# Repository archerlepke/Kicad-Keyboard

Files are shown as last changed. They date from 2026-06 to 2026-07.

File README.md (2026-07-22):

# Custom 60% Keyboard From Scratch

A custom mechanical keyboard designed from scratch in KiCad — schematic, PCB, and supporting files.

The goal of this repo is to document and archive my completed work on this project.

## Current Status

> **Manufacturing & Physical Assembly** — The PCB design is complete and the board has been sent to manufacturing.

Future Plans:
- soldering components & microcontroller from digikey(already bought and delivered)
- 3D Print keyboard case
- install switches & keycaps (already bought and on hand)
- install firmware (QMK)

## Renders & PCB Design

The case for the keyboard has been designed and needs to be 3D printed.

**SolidWorks renders of completed case & PCB:**

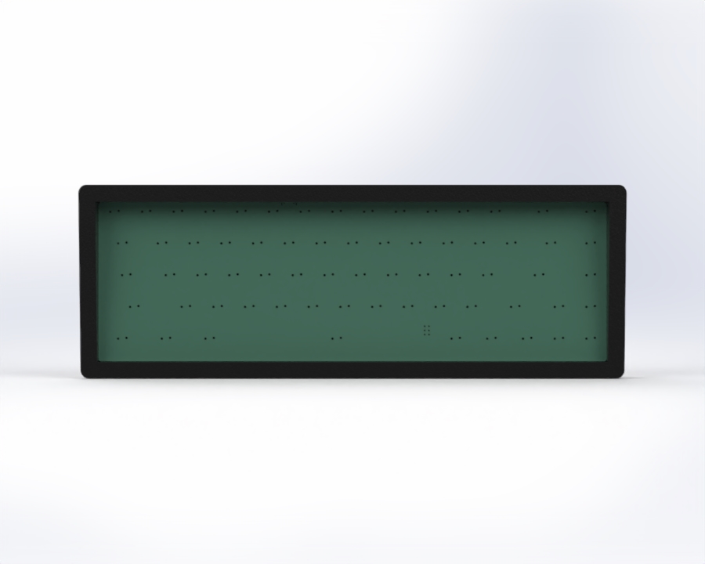
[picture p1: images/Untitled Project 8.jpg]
Render 2


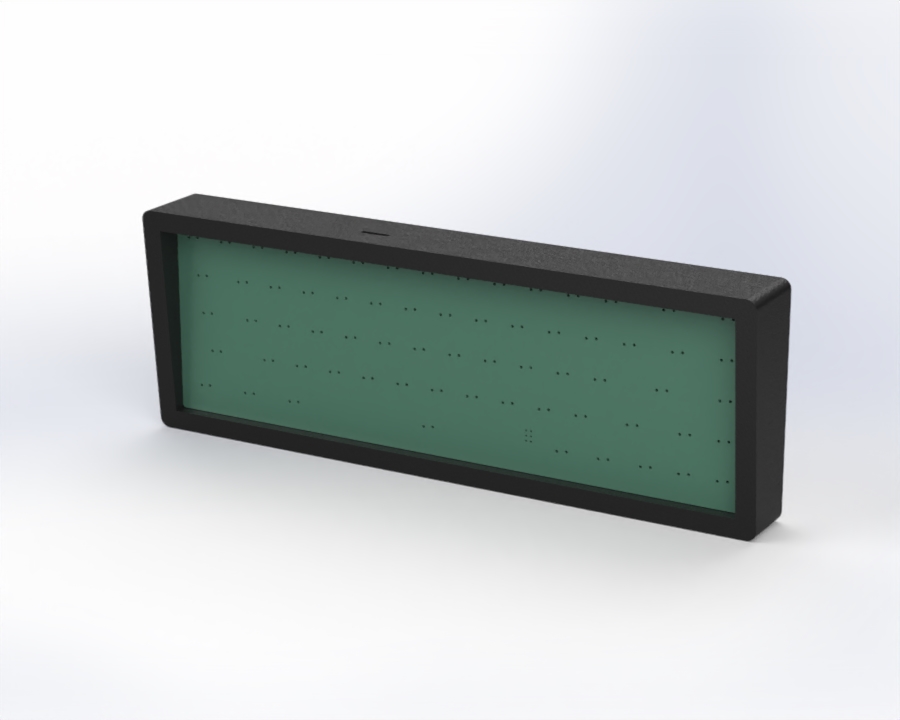
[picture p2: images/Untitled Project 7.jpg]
Render 1


**KiCad renders:**

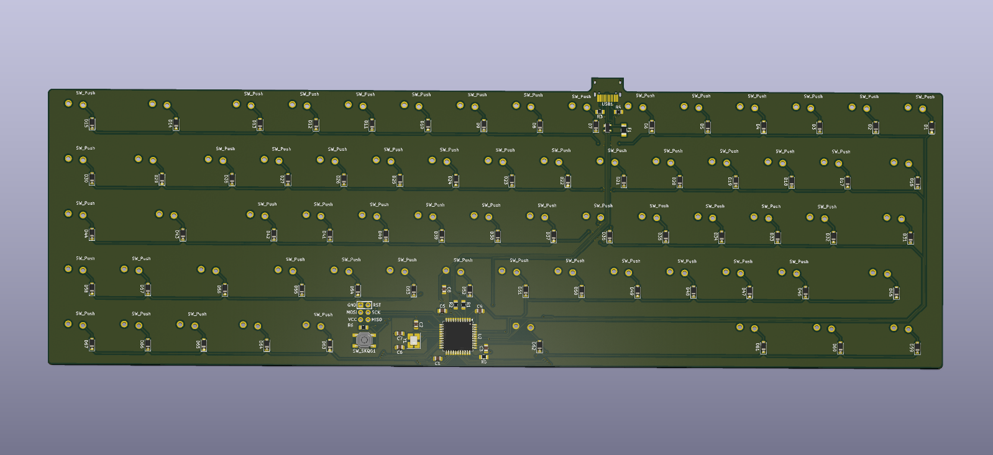
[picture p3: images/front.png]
KiCad Render 1


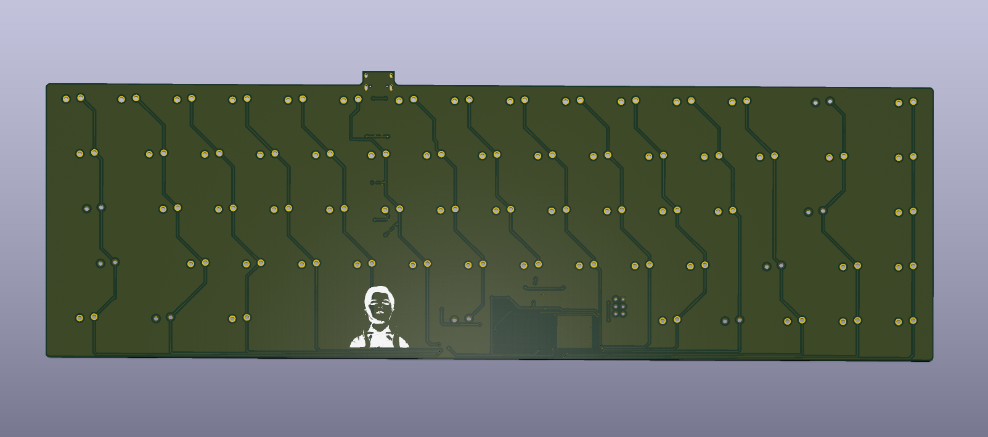
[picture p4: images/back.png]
KiCad Render 2


**KiCad PCB editor view & schematic:**

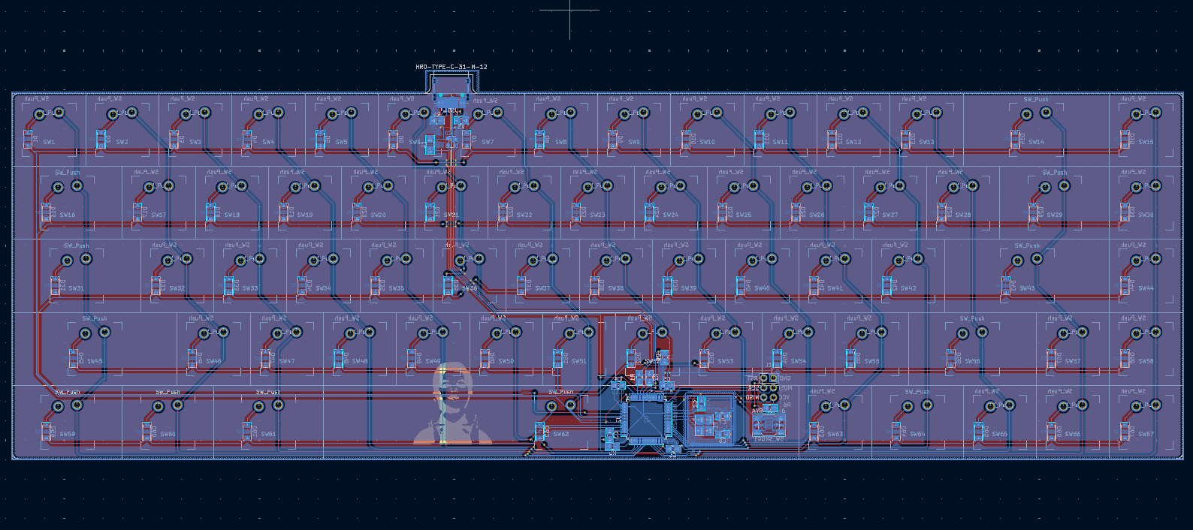
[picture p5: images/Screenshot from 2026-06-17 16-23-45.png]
PCB view 1


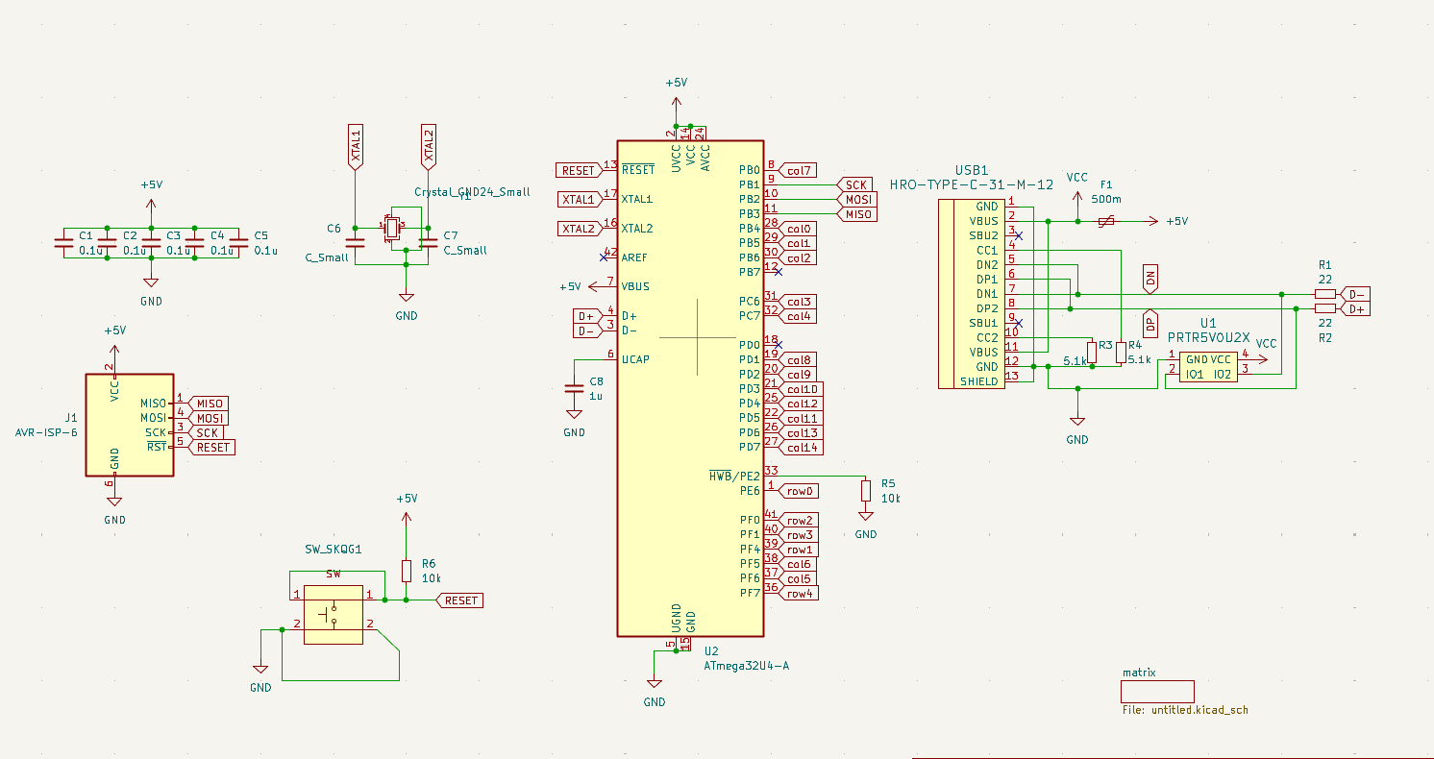
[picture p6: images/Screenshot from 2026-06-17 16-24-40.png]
PCB view 2


## About the Build

The goal of this build was to expand my electronics knowledge while physically creating a project I'd be proud of. This keyboard was designed following the excellent guide by Masterzen, [**Designing a keyboard from scratch**](https://www.masterzen.fr/2020/05/03/designing-a-keyboard-part-1/).

## Repository Structure

```
Keyboard/      KiCad project — open Keyboard/Keyboard.kicad_pro
libraries/     All footprint & symbol libraries (bundled, project-relative paths)
production/    Gerbers, drill files, and BOM as sent to manufacturing
cad/           STEP export and SolidWorks files for the case
images/        Renders and screenshots
```

## Opening the Project

```
git clone https://github.com/archerlepke/Kicad-Keyboard.git
```

Open `Keyboard/Keyboard.kicad_pro` in KiCad (v7 or newer). All custom libraries are
included in the repo and referenced with project-relative paths, so no library
setup is required.

## Library Credits

- [MX_Alps_Hybrid](https://github.com/ai03-2725/MX_Alps_Hybrid) — switch footprints & symbols by ai03
- [Type-C](https://github.com/ai03-2725/Type-C.pretty) — USB-C footprints & symbols by ai03
- [random-keyboard-parts](https://github.com/ai03-2725/random-keyboard-parts.pretty) — misc keyboard parts by ai03

## Tools Used

- **KiCad** — schematic capture and PCB design
- **SolidWorks** — 3D modeling
- **SolidWorks Visualize** — renders
- **QMK** — keyboard firmware (planned)

---

*This is an ongoing project*

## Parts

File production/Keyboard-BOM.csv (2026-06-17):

Id | Designator | Footprint | Quantity | Designation | Supplier and ref
1 | C1, C2, C3, C4, C5 | C_0805_2012Metric_Pad1.15x1.40mm_HandSolder | 5 | 0.1u
2 | C6, C7 | C_0805_2012Metric_Pad1.15x1.40mm_HandSolder | 2 | C_Small
3 | C8 | C_0805_2012Metric_Pad1.15x1.40mm_HandSolder | 1 | 1u
4 | D1, D2, D3, D4, D5, D6, D7, D8, D9, D10, D11, D12, D13, D14, D15, D16, D17, D18, D19, D20, D21, D22, D23, D24, D25, D26, D27, D28, D29, D30, D31, D32, D33, D34, D35, D36, D37, D38, D39, D40, D41, D42, D43, D44, D45, D46, D47, D48, D49, D50, D51, D52, D53, D54, D55, D56, D57, D58, D59, D60, D61, D62, D63, D64, D65, D66, D67 | D_SOD-123 | 67 | D
5 | F1 | Fuse_1206_3216Metric_Pad1.42x1.75mm_HandSolder | 1 | 500m
6 | J1 | Reset_Pretty-Mask | 1 | AVR-ISP-6
7 | R1, R2 | R_0805_2012Metric_Pad1.15x1.40mm_HandSolder | 2 | 22
8 | R3, R4 | R_0805_2012Metric_Pad1.15x1.40mm_HandSolder | 2 | 5.1k
9 | R5, R6 | R_0805_2012Metric_Pad1.15x1.40mm_HandSolder | 2 | 10k
10 | REF** | Untitled | 1 | Untitled
11 | SW1, SW2, SW3, SW4, SW5, SW6, SW7, SW8, SW9, SW10, SW11, SW12, SW13, SW15, SW17, SW18, SW19, SW20, SW21, SW22, SW23, SW24, SW25, SW26, SW27, SW28, SW30, SW32, SW33, SW34, SW35, SW36, SW37, SW38, SW39, SW40, SW41, SW42, SW44, SW46, SW47, SW48, SW49, SW50, SW51, SW52, SW53, SW54, SW55, SW57, SW58, SW63, SW65, SW66, SW67 | ALPS-1U | 55 | SW_Push
12 | SW14 | ALPS-2U | 1 | SW_Push
13 | SW16, SW29, SW59, SW61 | ALPS-1.5U | 4 | SW_Push
14 | SW31, SW56 | ALPS-1.75U | 2 | SW_Push
15 | SW43, SW45 | ALPS-2.25U | 2 | SW_Push
16 | SW60, SW64 | ALPS-1.25U | 2 | SW_Push
17 | SW62 | ALPS-6.5U | 1 | SW_Push
18 | SW_SKQG1 | SW_SPST_SKQG_WithStem | 1 | ~
19 | U1 | SOT143B | 1 | PRTR5V0U2X
20 | U2 | TQFP-44_10x10mm_P0.8mm | 1 | ATmega32U4-A
21 | USB1 | HRO-TYPE-C-31-M-12-HandSoldering | 1 | HRO-TYPE-C-31-M-12
22 | Y1 | Crystal_SMD_3225-4Pin_3.2x2.5mm_HandSoldering | 1 | Crystal_GND24_Small | got

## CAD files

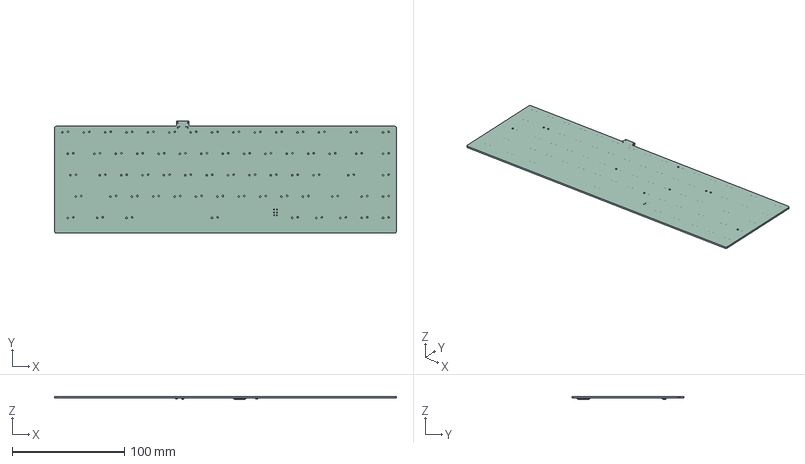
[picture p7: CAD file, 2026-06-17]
Keyboard/.step
304.8 x 100.0 x 2.70 mm
SOT-143
Fuse_1206_3216Metric
Crystal_SMD_3225-4Pin_3.2x2.5mm
TQFP-44_10x10mm_P0.8mm
Keyboard_PCB

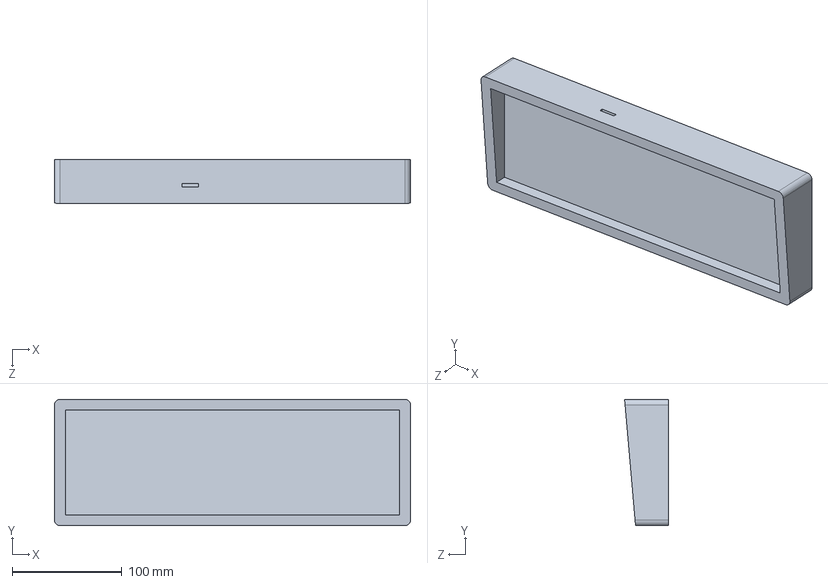
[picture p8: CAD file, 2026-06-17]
cad/dumb.SLDPRT
324.8 x 115.2 x 40.0 mm

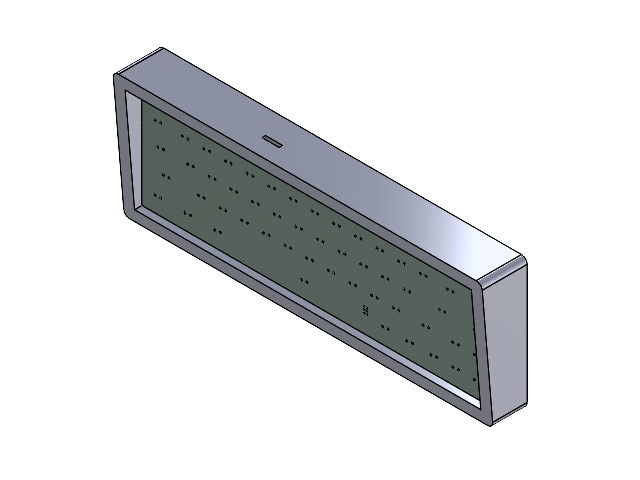
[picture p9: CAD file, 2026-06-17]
cad/Assembly.SLDASM
dumb
SOT-143.step
Fuse_1206_3216Metric.step
Crystal_SMD_3225-4Pin_3.2x2.5mm.step
TQFP-44_10x10mm_P0.8mm.step
Keyboard_PCB.step

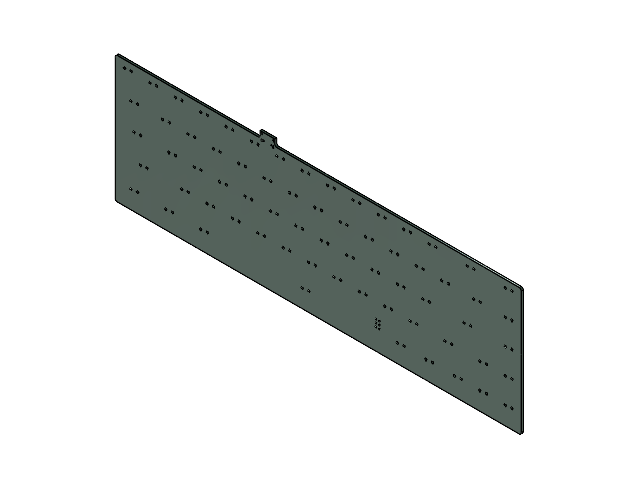
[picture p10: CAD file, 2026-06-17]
cad/part.SLDASM
SOT-143.step
Fuse_1206_3216Metric.step
Crystal_SMD_3225-4Pin_3.2x2.5mm.step
TQFP-44_10x10mm_P0.8mm.step
Keyboard_PCB.step

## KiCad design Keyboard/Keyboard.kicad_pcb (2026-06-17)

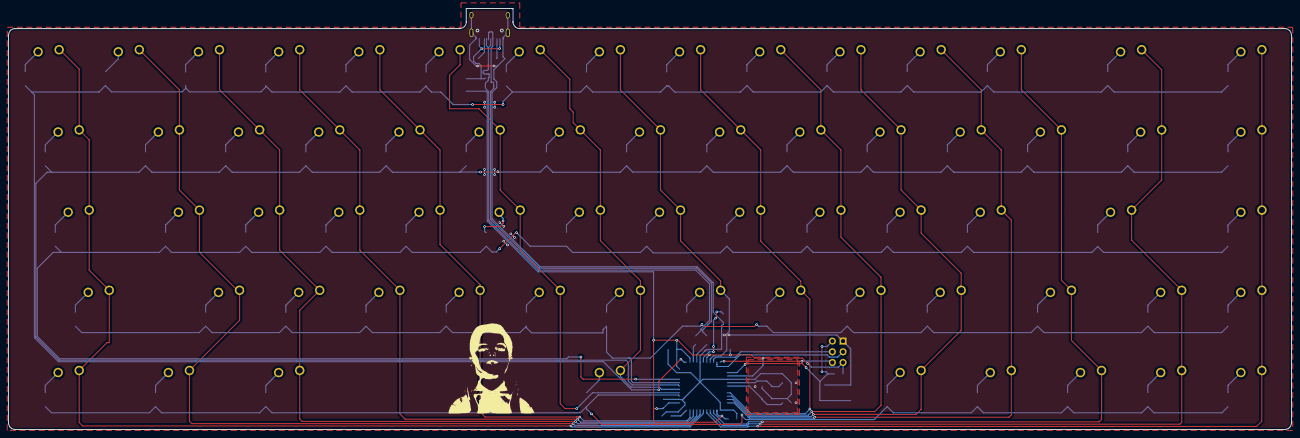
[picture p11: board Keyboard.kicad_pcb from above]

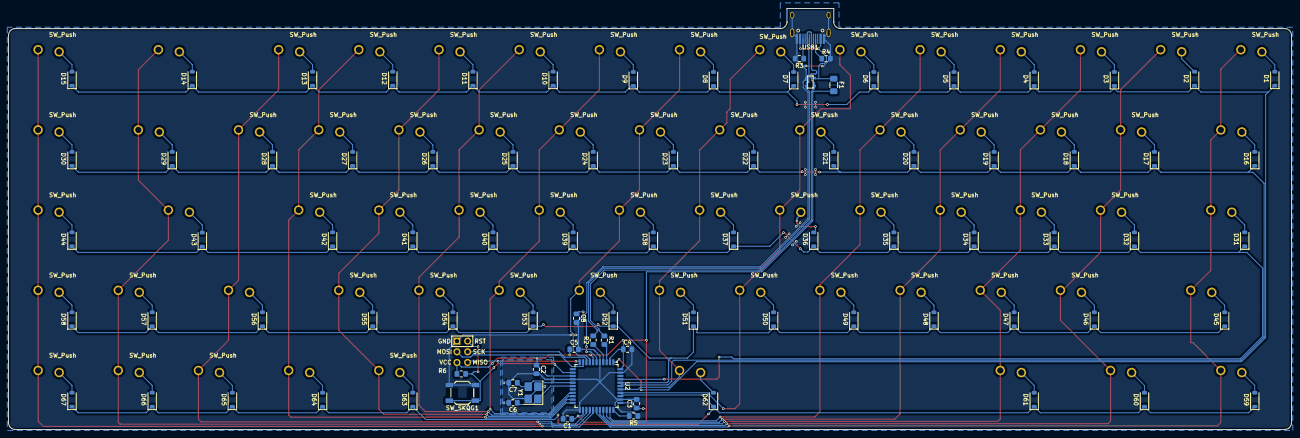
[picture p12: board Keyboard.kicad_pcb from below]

Board: 2 copper layers, 304.8 x 100.0 mm, 155 parts (88 on the bottom side), 104 nets.

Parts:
C1, C2, C3, C4, C5: 0.1u; C_0805_2012Metric_Pad1.15x1.40mm_HandSolder
C6, C7: C_Small; C_0805_2012Metric_Pad1.15x1.40mm_HandSolder
C8: 1u; C_0805_2012Metric_Pad1.15x1.40mm_HandSolder
D1, D2, D3, D4, D5, D6, D7, D8, D9, D10, D11, D12, D13, D14, D15, D16, D17, D18, D19, D20, D21, D22, D23, D24, D25, D26, D27, D28, D29, D30, D31, D32, D33, D34, D35, D36, D37, D38, D39, D40, D41, D42, D43, D44, D45, D46, D47, D48, D49, D50, D51, D52, D53, D54, D55, D56, D57, D58, D59, D60, D61, D62, D63, D64, D65, D66, D67: D; D_SOD-123
F1: 500m; Fuse_1206_3216Metric_Pad1.42x1.75mm_HandSolder
J1: AVR-ISP-6; Reset_Pretty-Mask
R1, R2: 22; R_0805_2012Metric_Pad1.15x1.40mm_HandSolder
R3, R4: 5.1k; R_0805_2012Metric_Pad1.15x1.40mm_HandSolder
R5, R6: 10k; R_0805_2012Metric_Pad1.15x1.40mm_HandSolder
SW1, SW2, SW3, SW4, SW5, SW6, SW7, SW8, SW9, SW10, SW11, SW12, SW13, SW15, SW17, SW18, SW19, SW20, SW21, SW22, SW23, SW24, SW25, SW26, SW27, SW28, SW30, SW32, SW33, SW34, SW35, SW36, SW37, SW38, SW39, SW40, SW41, SW42, SW44, SW46, SW47, SW48, SW49, SW50, SW51, SW52, SW53, SW54, SW55, SW57, SW58, SW63, SW65, SW66, SW67: SW_Push; ALPS-1U
SW14: SW_Push; ALPS-2U
SW16, SW29, SW59, SW61: SW_Push; ALPS-1.5U
SW31, SW56: SW_Push; ALPS-1.75U
SW43, SW45: SW_Push; ALPS-2.25U
SW60, SW64: SW_Push; ALPS-1.25U
SW62: SW_Push; ALPS-6.5U
SW_SKQG1: SW_SPST_SKQG_WithStem
U1: PRTR5V0U2X; SOT143B
U2: ATmega32U4-A; TQFP-44_10x10mm_P0.8mm
USB1: HRO-TYPE-C-31-M-12; HRO-TYPE-C-31-M-12-HandSoldering
Y1: Crystal_GND24_Small; Crystal_SMD_3225-4Pin_3.2x2.5mm_HandSoldering

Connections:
+5V: C1.1, C2.1, C3.1, C4.1, C5.1, F1.2, J1.2 (VCC), R6.1, U2.2 (UVCC), U2.7 (VBUS), U2.14 (VCC), U2.24 (AVCC), U2.34 (VCC), U2.44 (AVCC)
D+: R2.1, U2.4 (D+)
D-: R1.2, U2.3 (D-)
DN: R1.1, U1.3 (IO2), USB1.5 (DN2), USB1.7 (DN1)
DP: R2.2, U1.2 (IO1), USB1.6 (DP1), USB1.8 (DP2)
GND: C1.2, C2.2, C3.2, C4.2, C5.2, C6.2, C7.2, C8.2, J1.6 (GND), R3.2, R4.2, R5.1, SW_SKQG1.2, U1.1 (GND), U2.5 (UGND), U2.15 (GND), U2.23 (GND), U2.35 (GND), U2.43 (GND), USB1.1 (GND), USB1.12 (GND), USB1.13 (SHIELD), Y1.2, Y1.4
MISO: J1.1 (MISO), U2.11 (PB3)
MOSI: J1.4 (MOSI), U2.10 (PB2)
unnamed: D1.2 (A), SW1.1
unnamed: D2.2 (A), SW2.1
unnamed: D3.2 (A), SW3.1
unnamed: D4.2 (A), SW4.1
unnamed: D5.2 (A), SW5.1
unnamed: D6.2 (A), SW6.1
unnamed: D7.2 (A), SW7.1
unnamed: D8.2 (A), SW8.1
unnamed: D9.2 (A), SW9.1
unnamed: D10.2 (A), SW10.1
unnamed: D11.2 (A), SW11.1
unnamed: D12.2 (A), SW12.1
unnamed: D13.2 (A), SW13.1
unnamed: D14.2 (A), SW14.1
unnamed: D15.2 (A), SW15.1
unnamed: D16.2 (A), SW16.1
unnamed: D17.2 (A), SW17.1
unnamed: D18.2 (A), SW18.1
unnamed: D19.2 (A), SW19.1
unnamed: D20.2 (A), SW20.1
unnamed: D21.2 (A), SW21.1
unnamed: D22.2 (A), SW22.1
unnamed: D23.2 (A), SW23.1
unnamed: D24.2 (A), SW24.1
unnamed: D25.2 (A), SW25.1
unnamed: D26.2 (A), SW26.1
unnamed: D27.2 (A), SW27.1
unnamed: D28.2 (A), SW28.1
unnamed: D29.2 (A), SW29.1
unnamed: D30.2 (A), SW30.1
unnamed: D31.2 (A), SW31.1
unnamed: D32.2 (A), SW32.1
unnamed: D33.2 (A), SW33.1
unnamed: D34.2 (A), SW34.1
unnamed: D35.2 (A), SW35.1
unnamed: D36.2 (A), SW36.1
unnamed: D37.2 (A), SW37.1
unnamed: D38.2 (A), SW38.1
unnamed: D39.2 (A), SW39.1
unnamed: D40.2 (A), SW40.1
unnamed: D41.2 (A), SW41.1
unnamed: D42.2 (A), SW42.1
unnamed: D43.2 (A), SW43.1
unnamed: D44.2 (A), SW44.1
unnamed: D45.2 (A), SW45.1
unnamed: D46.2 (A), SW46.1
unnamed: D47.2 (A), SW47.1
unnamed: D48.2 (A), SW48.1
unnamed: D49.2 (A), SW49.1
unnamed: D50.2 (A), SW50.1
unnamed: D51.2 (A), SW51.1
unnamed: D52.2 (A), SW52.1
unnamed: D53.2 (A), SW53.1
unnamed: D54.2 (A), SW54.1
unnamed: D55.2 (A), SW55.1
unnamed: D56.2 (A), SW56.1
unnamed: D57.2 (A), SW57.1
unnamed: D58.2 (A), SW58.1
unnamed: D59.2 (A), SW59.1
unnamed: D60.2 (A), SW60.1
unnamed: D61.2 (A), SW61.1
unnamed: D62.2 (A), SW62.1
unnamed: D63.2 (A), SW63.1
unnamed: D64.2 (A), SW64.1
unnamed: D65.2 (A), SW65.1
unnamed: D66.2 (A), SW66.1
unnamed: D67.2 (A), SW67.1
unnamed: C8.1, U2.6 (UCAP)
unnamed: R5.2, U2.33 (~HWB/PE2)
unnamed: R4.1, USB1.4 (CC1)
unnamed: R3.1, USB1.10 (CC2)
RESET: J1.5 (~RST), R6.2, SW_SKQG1.1, U2.13 (~RESET)
SCK: J1.3 (SCK), U2.9 (PB1)
VCC: F1.1, U1.4 (VCC), USB1.2 (VBUS), USB1.11 (VBUS)
XTAL1: C6.1, U2.17 (XTAL1), Y1.1
XTAL2: C7.1, U2.16 (XTAL2), Y1.3
col0: SW1.2, SW16.2, SW31.2, SW45.2, SW59.2, U2.28 (PB4)
col1: SW2.2, SW17.2, SW32.2, SW46.2, SW60.2, U2.29 (PB5)
col2: SW3.2, SW18.2, SW33.2, SW47.2, SW61.2, U2.30 (PB6)
col3: SW4.2, SW19.2, SW34.2, SW48.2, U2.31 (PC6)
col4: SW5.2, SW20.2, SW35.2, SW49.2, U2.32 (PC7)
col5: SW6.2, SW21.2, SW36.2, SW50.2, U2.37 (PF6)
col6: SW7.2, SW22.2, SW37.2, SW51.2, SW62.2, U2.38 (PF5)
col7: SW8.2, SW23.2, SW38.2, SW52.2, U2.8 (PB0)
col8: SW9.2, SW24.2, SW39.2, SW53.2, U2.19 (PD1)
col9: SW10.2, SW25.2, SW40.2, SW54.2, U2.20 (PD2)
col10: SW11.2, SW26.2, SW41.2, SW55.2, SW63.2, U2.21 (PD3)
col11: SW12.2, SW27.2, SW42.2, SW64.2, U2.22 (PD5)
col12: SW13.2, SW28.2, SW56.2, SW65.2, U2.25 (PD4)
col13: SW14.2, SW29.2, SW43.2, SW57.2, SW66.2, U2.26 (PD6)
col14: SW15.2, SW30.2, SW44.2, SW58.2, SW67.2, U2.27 (PD7)
row0: D1.1 (K), D2.1 (K), D3.1 (K), D4.1 (K), D5.1 (K), D6.1 (K), D7.1 (K), D8.1 (K), D9.1 (K), D10.1 (K), D11.1 (K), D12.1 (K), D13.1 (K), D14.1 (K), D15.1 (K), U2.1 (PE6)
row1: D16.1 (K), D17.1 (K), D18.1 (K), D19.1 (K), D20.1 (K), D21.1 (K), D22.1 (K), D23.1 (K), D24.1 (K), D25.1 (K), D26.1 (K), D27.1 (K), D28.1 (K), D29.1 (K), D30.1 (K), U2.39 (PF4)
row2: D31.1 (K), D32.1 (K), D33.1 (K), D34.1 (K), D35.1 (K), D36.1 (K), D37.1 (K), D38.1 (K), D39.1 (K), D40.1 (K), D41.1 (K), D42.1 (K), D43.1 (K), D44.1 (K), U2.41 (PF0)
row3: D45.1 (K), D46.1 (K), D47.1 (K), D48.1 (K), D49.1 (K), D50.1 (K), D51.1 (K), D52.1 (K), D53.1 (K), D54.1 (K), D55.1 (K), D56.1 (K), D57.1 (K), D58.1 (K), U2.40 (PF1)
row4: D59.1 (K), D60.1 (K), D61.1 (K), D62.1 (K), D63.1 (K), D64.1 (K), D65.1 (K), D66.1 (K), D67.1 (K), U2.36 (PF7)

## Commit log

2026-06-17 Initial commit - Adding already completed files
    [.step, Final-Project.kicad_pcb, Final-Project.kicad_sch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]
2026-07-22 clean restructure
    [Assembly.SLDASM, Final-Project.kicad_pcb, Final-Project.kicad_sch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]
